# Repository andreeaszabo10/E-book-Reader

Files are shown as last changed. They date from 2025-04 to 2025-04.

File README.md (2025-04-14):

Szabo Cristina-Andreea
# E-book Reader
The project (Openbook) is an E-book reader built around the ESP32-C6-WROOM-1-N8 microcontroller, which integrates Wi-Fi and Bluetooth Low Energy functionality. It is responsible for managing communication between the connected components, sensor data acquisition, and display handling. The E-book reader has a 7.5-inch e-paper display, USB-C charging, a Li-Po battery, and 3 buttons.

## Block diagram:
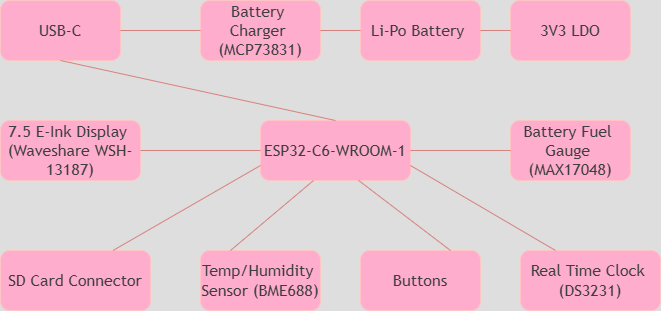
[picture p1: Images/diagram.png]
Block Diagram:

## BOM - Bill of materials
| Component | Device | Link | Datasheet |
|---|---|---|---|
| BOOT_BUTTON | BUTTON_CUSYOMV1 | [Link](https://ro.mouser.com/ProductDetail/Panasonic/EVQ-P7L01P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) | [Datasheet](https://componentsearchengine.com/Datasheets/2/EVQP7L01P.pdf) |
| C1 | ESP32_WROVER_EAGLE-LTSPICE_CC0402 | [Link](https://ro.mouser.com/ProductDetail/YAGEO/CC0402MRX5R5BB106?qs=zEY9bCHj09eCmUJdZuS5Lg%3D%3D)  | [Datasheet](https://componentsearchengine.com/Datasheets/2/CC0402MRX5R5BB106.pdf) |
| C1_BAT | ESP32_WROVER_EAGLE-LTSPICE_CC0402 | [Link](https://ro.mouser.com/ProductDetail/YAGEO/CC0402MRX5R5BB106?qs=zEY9bCHj09eCmUJdZuS5Lg%3D%3D)  | [Datasheet](https://componentsearchengine.com/Datasheets/2/CC0402MRX5R5BB106.pdf) |
| C1_BAT1 | EAGLE-LTSPICE_CC0402 | [Link](https://ro.mouser.com/ProductDetail/YAGEO/CC0402MRX5R5BB106?qs=zEY9bCHj09eCmUJdZuS5Lg%3D%3D)  | [Datasheet](https://componentsearchengine.com/Datasheets/2/CC0402MRX5R5BB106.pdf) |
| C1_BAT2 | EAGLE-LTSPICE_CC0402 | [Link](https://ro.mouser.com/ProductDetail/YAGEO/CC0402MRX5R5BB106?qs=zEY9bCHj09eCmUJdZuS5Lg%3D%3D)  | [Datasheet](https://componentsearchengine.com/Datasheets/2/CC0402MRX5R5BB106.pdf) |
| C2 | ESP32_WROVER_EAGLE-LTSPICE_CC0402 | [Link](https://ro.mouser.com/ProductDetail/YAGEO/CC0402MRX5R5BB106?qs=zEY9bCHj09eCmUJdZuS5Lg%3D%3D)  | [Datasheet](https://componentsearchengine.com/Datasheets/2/CC0402MRX5R5BB106.pdf) |
| C2_BAT | ESP32_WROVER_EAGLE-LTSPICE_CC0402 | [Link](https://ro.mouser.com/ProductDetail/YAGEO/CC0402MRX5R5BB106?qs=zEY9bCHj09eCmUJdZuS5Lg%3D%3D)  | [Datasheet](https://componentsearchengine.com/Datasheets/2/CC0402MRX5R5BB106.pdf) |
| C3 | RCL_CPOL-EUCT3528 | [Link](https://ro.mouser.com/ProductDetail/YAGEO/CC0402MRX5R5BB106?qs=zEY9bCHj09eCmUJdZuS5Lg%3D%3D)  | [Datasheet](https://componentsearchengine.com/Datasheets/2/CC0402MRX5R5BB106.pdf) |
| C4 | ESP32_WROVER_EAGLE-LTSPICE_CC0402 | [Link](https://ro.mouser.com/ProductDetail/YAGEO/CC0402MRX5R5BB106?qs=zEY9bCHj09eCmUJdZuS5Lg%3D%3D)  | [Datasheet](https://componentsearchengine.com/Datasheets/2/CC0402MRX5R5BB106.pdf) |
| C4_USB | ESP32_WROVER_EAGLE-LTSPICE_CC0402 | [Link](https://ro.mouser.com/ProductDetail/YAGEO/CC0402MRX5R5BB106?qs=zEY9bCHj09eCmUJdZuS5Lg%3D%3D)  | [Datasheet](https://componentsearchengine.com/Datasheets/2/CC0402MRX5R5BB106.pdf) |
| C5 | ESP32_WROVER_EAGLE-LTSPICE_CC0402 | [Link](https://ro.mouser.com/ProductDetail/YAGEO/CC0402MRX5R5BB106?qs=zEY9bCHj09eCmUJdZuS5Lg%3D%3D)  | [Datasheet](https://componentsearchengine.com/Datasheets/2/CC0402MRX5R5BB106.pdf) |
| C5_USB | ESP32_WROVER_EAGLE-LTSPICE_CC0402 | [Link](https://ro.mouser.com/ProductDetail/YAGEO/CC0402MRX5R5BB106?qs=zEY9bCHj09eCmUJdZuS5Lg%3D%3D)  | [Datasheet](https://componentsearchengine.com/Datasheets/2/CC0402MRX5R5BB106.pdf) |
| C6 | ESP32_WROVER_EAGLE-LTSPICE_CC0402 | [Link](https://ro.mouser.com/ProductDetail/YAGEO/CC0402MRX5R5BB106?qs=zEY9bCHj09eCmUJdZuS5Lg%3D%3D)  | [Datasheet](https://componentsearchengine.com/Datasheets/2/CC0402MRX5R5BB106.pdf) |
| C7 | ESP32_WROVER_EAGLE-LTSPICE_CC0402 | [Link](https://ro.mouser.com/ProductDetail/YAGEO/CC0402MRX5R5BB106?qs=zEY9bCHj09eCmUJdZuS5Lg%3D%3D)  | [Datasheet](https://componentsearchengine.com/Datasheets/2/CC0402MRX5R5BB106.pdf) |
| C8 | ESP32_WROVER_EAGLE-LTSPICE_CC0402 | [Link](https://ro.mouser.com/ProductDetail/YAGEO/CC0402MRX5R5BB106?qs=zEY9bCHj09eCmUJdZuS5Lg%3D%3D)  | [Datasheet](https://componentsearchengine.com/Datasheets/2/CC0402MRX5R5BB106.pdf) |
| C9 | EAGLE-LTSPICE_CC0402 | [Link](https://ro.mouser.com/ProductDetail/YAGEO/CC0402MRX5R5BB106?qs=zEY9bCHj09eCmUJdZuS5Lg%3D%3D)  | [Datasheet](https://componentsearchengine.com/Datasheets/2/CC0402MRX5R5BB106.pdf) |
| C10 | ESP32_WROVER_EAGLE-LTSPICE_CC0402 | [Link](https://ro.mouser.com/ProductDetail/YAGEO/CC0402MRX5R5BB106?qs=zEY9bCHj09eCmUJdZuS5Lg%3D%3D)  | [Datasheet](https://componentsearchengine.com/Datasheets/2/CC0402MRX5R5BB106.pdf) |
| C10_SUPERCAP | CPH3225A | [Link](https://ro.mouser.com/ProductDetail/Seiko-Semiconductors/CPH3225A?qs=3etwrb1wR%252BhUOph6lAO7eg%3D%3D) | [Datasheet](https://ro.mouser.com/datasheet/2/360/Seiko_Instruments_MicroBattery_E_20230330_2024Jan_-3561061.pdf) |
| CHANGE_BUTTON | BUTTON_CUSYOMV1 | [Link](https://ro.mouser.com/ProductDetail/Panasonic/EVQ-P7L01P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) | [Datasheet](https://componentsearchengine.com/Datasheets/2/EVQP7L01P.pdf) |
| C_DELAY | ESP32_WROVER_EAGLE-LTSPICE_CC0402 | [Link](https://ro.mouser.com/ProductDetail/YAGEO/CC0402MRX5R5BB106?qs=zEY9bCHj09eCmUJdZuS5Lg%3D%3D)  | [Datasheet](https://componentsearchengine.com/Datasheets/2/CC0402MRX5R5BB106.pdf) |
| D1 | USBLC6-2SC6Y | [Link](https://ro.mouser.com/ProductDetail/STMicroelectronics/USBLC6-2SC6Y?qs=gNDSiZmRJS%2FOgDexvXkdow%3D%3D) | [Datasheet](https://ro.mouser.com/datasheet/2/389/usblc6_2sc6y-1852505.pdf) |
| D2 | ESP32_WROVER_AVX...SD0805S020S1R0_AVX_... | [Link](https://eu.mouser.com/ProductDetail/KYOCERA-AVX/SD0805S020S1R0?qs=jCA%252BPfw4LHbpkAoSnwrdjw%3D%3D) | [Datasheet](http://datasheets.avx.com/schottky.pdf) |
| D3 | MBR0530 | [Link](https://www.snapeda.com/parts/MBR0530/Onsemi/view-part/?ref=eda) | [Datasheet](https://www.snapeda.com/parts/MBR0530/Onsemi/view-part/?ref=eda) |
| D4 | MBR0530 | [Link](https://www.snapeda.com/parts/MBR0530/Onsemi/view-part/?ref=eda) | [Datasheet](https://www.snapeda.com/parts/MBR0530/Onsemi/view-part/?ref=eda) |
| D5 | MBR0530 | [Link](https://www.snapeda.com/parts/MBR0530/Onsemi/view-part/?ref=eda) | [Datasheet](https://www.snapeda.com/parts/MBR0530/Onsemi/view-part/?ref=eda) |
| D6 | PGB1010603MR | [Link](https://www.snapeda.com/parts/PGB1010603MR/Littelfuse/view-part/?ref=eda) | [Datasheet](https://www.snapeda.com/parts/PGB1010603MR/Littelfuse/view-part/?ref=eda) |
| D7 | ESP32_WROVER_AVX---SD0805S020S1R0_AVX_... | [Link](https://eu.mouser.com/ProductDetail/KYOCERA-AVX/SD0805S020S1R0?qs=jCA%252BPfw4LHbpkAoSnwrdjw%3D%3D) | [Datasheet](http://datasheets.avx.com/schottky.pdf) |
| D8 | PGB1010603MR | [Link](https://www.snapeda.com/parts/PGB1010603MR/Littelfuse/view-part/?ref=eda) | [Datasheet](https://www.snapeda.com/parts/PGB1010603MR/Littelfuse/view-part/?ref=eda) |
| D9 | PGB1010603MR | [Link](https://www.snapeda.com/parts/PGB1010603MR/Littelfuse/view-part/?ref=eda) | [Datasheet](https://www.snapeda.com/parts/PGB1010603MR/Littelfuse/view-part/?ref=eda) |
| D10 | PGB1010603MR | [Link](https://www.snapeda.com/parts/PGB1010603MR/Littelfuse/view-part/?ref=eda) | [Datasheet](https://www.snapeda.com/parts/PGB1010603MR/Littelfuse/view-part/?ref=eda) |
| D11 | PGB1010603MR | [Link](https://www.snapeda.com/parts/PGB1010603MR/Littelfuse/view-part/?ref=eda) | [Datasheet](https://www.snapeda.com/parts/PGB1010603MR/Littelfuse/view-part/?ref=eda) |
| D12 | PGB1010603MR | [Link](https://www.snapeda.com/parts/PGB1010603MR/Littelfuse/view-part/?ref=eda) | [Datasheet](https://www.snapeda.com/parts/PGB1010603MR/Littelfuse/view-part/?ref=eda) |
| EPD_C1 | ESP32_WROVER_EAGLE-LTSPICE_CC0402 | [Link](https://ro.mouser.com/ProductDetail/YAGEO/CC0402MRX5R5BB106?qs=zEY9bCHj09eCmUJdZuS5Lg%3D%3D)  | [Datasheet](https://componentsearchengine.com/Datasheets/2/CC0402MRX5R5BB106.pdf) |
| EPD_C2 | ESP32_WROVER_EAGLE-LTSPICE_CC0402 | [Link](https://ro.mouser.com/ProductDetail/YAGEO/CC0402MRX5R5BB106?qs=zEY9bCHj09eCmUJdZuS5Lg%3D%3D)  | [Datasheet](https://componentsearchengine.com/Datasheets/2/CC0402MRX5R5BB106.pdf) |
| EPD_C5 | ESP32_WROVER_EAGLE-LTSPICE_CC0402 | [Link](https://ro.mouser.com/ProductDetail/YAGEO/CC0402MRX5R5BB106?qs=zEY9bCHj09eCmUJdZuS5Lg%3D%3D)  | [Datasheet](https://componentsearchengine.com/Datasheets/2/CC0402MRX5R5BB106.pdf) |
| EPD_C6 | ESP32_WROVER_EAGLE-LTSPICE_CC0402 | [Link](https://ro.mouser.com/ProductDetail/YAGEO/CC0402MRX5R5BB106?qs=zEY9bCHj09eCmUJdZuS5Lg%3D%3D)  | [Datasheet](https://componentsearchengine.com/Datasheets/2/CC0402MRX5R5BB106.pdf) |
| EPD_C7 | ESP32_WROVER_EAGLE-LTSPICE_CC0402 | [Link](https://ro.mouser.com/ProductDetail/YAGEO/CC0402MRX5R5BB106?qs=zEY9bCHj09eCmUJdZuS5Lg%3D%3D)  | [Datasheet](https://componentsearchengine.com/Datasheets/2/CC0402MRX5R5BB106.pdf) |
| EPD_C8 | ESP32_WROVER_EAGLE-LTSPICE_CC0402 | [Link](https://ro.mouser.com/ProductDetail/YAGEO/CC0402MRX5R5BB106?qs=zEY9bCHj09eCmUJdZuS5Lg%3D%3D)  | [Datasheet](https://componentsearchengine.com/Datasheets/2/CC0402MRX5R5BB106.pdf) |
| EPD_C9 | ESP32_WROVER_EAGLE-LTSPICE_CC0402 | [Link](https://ro.mouser.com/ProductDetail/YAGEO/CC0402MRX5R5BB106?qs=zEY9bCHj09eCmUJdZuS5Lg%3D%3D)  | [Datasheet](https://componentsearchengine.com/Datasheets/2/CC0402MRX5R5BB106.pdf) |
| EPD_C10 | ESP32_WROVER_EAGLE-LTSPICE_CC0402 | [Link](https://ro.mouser.com/ProductDetail/YAGEO/CC0402MRX5R5BB106?qs=zEY9bCHj09eCmUJdZuS5Lg%3D%3D)  | [Datasheet](https://componentsearchengine.com/Datasheets/2/CC0402MRX5R5BB106.pdf) |
| EPD_C11 | ESP32_WROVER_EAGLE-LTSPICE_CC0402 | [Link](https://ro.mouser.com/ProductDetail/YAGEO/CC0402MRX5R5BB106?qs=zEY9bCHj09eCmUJdZuS5Lg%3D%3D)  | [Datasheet](https://componentsearchengine.com/Datasheets/2/CC0402MRX5R5BB106.pdf) |
| EPD_C12 | ESP32_WROVER_EAGLE-LTSPICE_CC0402 | [Link](https://ro.mouser.com/ProductDetail/YAGEO/CC0402MRX5R5BB106?qs=zEY9bCHj09eCmUJdZuS5Lg%3D%3D)  | [Datasheet](https://componentsearchengine.com/Datasheets/2/CC0402MRX5R5BB106.pdf) |
| IC1 | BD5229G-TR | [Link](https://ro.mouser.com/ProductDetail/ROHM-Semiconductor/BD5229G-TR?qs=4kLU8WoGk0vvnhrrYwdszw%3D%3D) | [Datasheet](https://fscdn.rohm.com/en/products/databook/datasheet/ic/power/voltage_detector/bd52xxg-e.pdf) |
| IC4 | XC6220A331MR-G | [Link](https://ro.mouser.com/ProductDetail/Torex-Semiconductor/XC6220A331MR-G?qs=AsjdqWjXhJ8ZSWznL1J0gg%3D%3D) | [Datasheet](https://ro.mouser.com/datasheet/2/760/xc6220-3371556.pdf) |
| J1 | FH34SRJ-24S-0.5SH_99_ | [Link](https://ro.mouser.com/ProductDetail/Hirose-Connector/FH34SRJ-24S-0.5SH99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) | [Datasheet](https://ro.mouser.com/datasheet/2/185/FH34SRJ_24S_0_5SH_99__CL0580_1255_6_99_2DDrawing_0-1615044.pdf) |
| J2 | USB4110-GF-A | [Link](https://ro.mouser.com/ProductDetail/GCT/USB4110-GF-A?qs=KUoIvG%2F9IlYiZvIXQjyJeA%3D%3D) | [Datasheet](https://ro.mouser.com/datasheet/2/837/GCT_USB4110_Product_Drawing___20k_cycles-3455479.pdf) |
| J3 | QWIIC_CONNECTORJS-1MM | [Link](https://ro.mouser.com/ProductDetail/SparkFun/PRT-14417?qs=wd5RIQLrsJhgdz%2FpmZ%2F3GQ%3D%3D) | [Datasheet](https://ro.mouser.com/datasheet/2/813/Qwiic_Connector_Datasheet-1223982.pdf) |
| J4 | 112A-TAAR-R03_ATTEND  | [Link](https://store.comet.srl.ro/Catalogue/Product/43497/) | [Datasheet](https://store.comet.srl.ro/Catalogue/Product/43497/) |
| L1 | 744043680IND_4828-WE-TPC_WRE | [Link](https://ro.mouser.com/ProductDetail/Wurth-Elektronik/744043680?qs=PGXP4M47uW6VkZq%252BkzjrHA%3D%3D) | [Datasheet](https://eu.mouser.com/ProductDetail/Wurth-Elektronik/744043680?qs=PGXP4M47uW6VkZq%252BkzjrHA%3D%3D) |
| PFMF.050.1 | ESP32C6_VARISTORCN1812 | [Link](https://ro.mouser.com/ProductDetail/KEMET/VE1812K401R050?qs=OycAS1CGnlizCtaoDVbQTA%3D%3D) | [Datasheet](https://www.mouser.co.uk/ProductDetail/EPCOS-TDK/B72520T0350K062?qs=dEfas%2FXlABIszF52uu7vrg%3D%3D) |
| Q1 | DMG2305UX-7 | [Link](https://ro.mouser.com/ProductDetail/Diodes-Incorporated/DMG2305UX-7?qs=L1DZKBg7t5F%2FNBHrjfxC%252Bg%3D%3D) | [Datasheet](https://www.diodes.com/assets/Datasheets/DMG2305UX.pdf) |
| Q2 | ESP32_WROVER_SPARKFUN-DISCRETESEMI_MOSFET_... | [Link](https://ro.mouser.com/ProductDetail/Diodes-Incorporated/DMG2305UX-7?qs=L1DZKBg7t5F%2FNBHrjfxC%252Bg%3D%3D) | [Datasheet](https://www.diodes.com/assets/Datasheets/DMG2305UX.pdf) |
| Q3 | D8 | [Link](https://ro.mouser.com/ProductDetail/Vishay-Semiconductors/SI1308EDL-T1-GE3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) | [Datasheet](https://componentsearchengine.com/part-view/SI1308EDL-T1-GE3/Vishay) |
| R1 | ESP32_WROVER_EAGLE-LTSPICE_RR0402 | [Link](https://ro.mouser.com/ProductDetail/YAGEO/RC0402FR-07100KL?qs=mnq%2FyloZIXzTlUn7JAHSWg%3D%3D) | [Datasheet](https://ro.mouser.com/datasheet/2/447/YAGEO_PYu_RC_Group_51_RoHS_L_12-3313492.pdf) |
| R1_PINH | ESP32_WROVER_EAGLE-LTSPICE_RR0402 | [Link](https://ro.mouser.com/ProductDetail/YAGEO/RC0402FR-07100KL?qs=mnq%2FyloZIXzTlUn7JAHSWg%3D%3D) | [Datasheet](https://ro.mouser.com/datasheet/2/447/YAGEO_PYu_RC_Group_51_RoHS_L_12-3313492.pdf) |
| R1_PINH1 | ESP32_WROVER_EAGLE-LTSPICE_RR0402 | [Link](https://ro.mouser.com/ProductDetail/YAGEO/RC0402FR-07100KL?qs=mnq%2FyloZIXzTlUn7JAHSWg%3D%3D) | [Datasheet](https://ro.mouser.com/datasheet/2/447/YAGEO_PYu_RC_Group_51_RoHS_L_12-3313492.pdf) |
| R1_BAT | ESP32_WROVER_EAGLE-LTSPICE_RR0402 | [Link](https://ro.mouser.com/ProductDetail/YAGEO/RC0402FR-07100KL?qs=mnq%2FyloZIXzTlUn7JAHSWg%3D%3D) | [Datasheet](https://ro.mouser.com/datasheet/2/447/YAGEO_PYu_RC_Group_51_RoHS_L_12-3313492.pdf) |
| R1_PWRUSB | ESP32_WROVER_EAGLE-LTSPICE_RR0402 | [Link](https://ro.mouser.com/ProductDetail/YAGEO/RC0402FR-07100KL?qs=mnq%2FyloZIXzTlUn7JAHSWg%3D%3D) | [Datasheet](https://ro.mouser.com/datasheet/2/447/YAGEO_PYu_RC_Group_51_RoHS_L_12-3313492.pdf) |
| R2 | ESP32_WROVER_EAGLE-LTSPICE_RR0402 | [Link](https://ro.mouser.com/ProductDetail/YAGEO/RC0402FR-07100KL?qs=mnq%2FyloZIXzTlUn7JAHSWg%3D%3D) | [Datasheet](https://ro.mouser.com/datasheet/2/447/YAGEO_PYu_RC_Group_51_RoHS_L_12-3313492.pdf) |
| R2_PINH | ESP32_WROVER_EAGLE-LTSPICE_RR0402 | [Link](https://ro.mouser.com/ProductDetail/YAGEO/RC0402FR-07100KL?qs=mnq%2FyloZIXzTlUn7JAHSWg%3D%3D) | [Datasheet](https://ro.mouser.com/datasheet/2/447/YAGEO_PYu_RC_Group_51_RoHS_L_12-3313492.pdf) |
| R2_PINH1 | ESP32_WROVER_EAGLE-LTSPICE_RR0402 | [Link](https://ro.mouser.com/ProductDetail/YAGEO/RC0402FR-07100KL?qs=mnq%2FyloZIXzTlUn7JAHSWg%3D%3D) | [Datasheet](https://ro.mouser.com/datasheet/2/447/YAGEO_PYu_RC_Group_51_RoHS_L_12-3313492.pdf) |
| R2_USB | ESP32_WROVER_EAGLE-LTSPICE_RR0402 | [Link](https://ro.mouser.com/ProductDetail/YAGEO/RC0402FR-07100KL?qs=mnq%2FyloZIXzTlUn7JAHSWg%3D%3D) | [Datasheet](https://ro.mouser.com/datasheet/2/447/YAGEO_PYu_RC_Group_51_RoHS_L_12-3313492.pdf) |
| R2_USB1 | ESP32_WROVER_EAGLE-LTSPICE_RR0402 | [Link](https://ro.mouser.com/ProductDetail/YAGEO/RC0402FR-07100KL?qs=mnq%2FyloZIXzTlUn7JAHSWg%3D%3D) | [Datasheet](https://ro.mouser.com/datasheet/2/447/YAGEO_PYu_RC_Group_51_RoHS_L_12-3313492.pdf) |
| R2_BAT | ESP32_WROVER_EAGLE-LTSPICE_RR0402 | [Link](https://ro.mouser.com/ProductDetail/YAGEO/RC0402FR-07100KL?qs=mnq%2FyloZIXzTlUn7JAHSWg%3D%3D) | [Datasheet](https://ro.mouser.com/datasheet/2/447/YAGEO_PYu_RC_Group_51_RoHS_L_12-3313492.pdf) |
| R3 | ESP32_WROVER_EAGLE-LTSPICE_RR0402 | [Link](https://ro.mouser.com/ProductDetail/YAGEO/RC0402FR-07100KL?qs=mnq%2FyloZIXzTlUn7JAHSWg%3D%3D) | [Datasheet](https://ro.mouser.com/datasheet/2/447/YAGEO_PYu_RC_Group_51_RoHS_L_12-3313492.pdf) |
| R4 | ESP32_WROVER_EAGLE-LTSPICE_RR0402 | [Link](https://ro.mouser.com/ProductDetail/YAGEO/RC0402FR-07100KL?qs=mnq%2FyloZIXzTlUn7JAHSWg%3D%3D) | [Datasheet](https://ro.mouser.com/datasheet/2/447/YAGEO_PYu_RC_Group_51_RoHS_L_12-3313492.pdf) |
| R5 | ESP32_WROVER_EAGLE-LTSPICE_RR0402 | [Link](https://ro.mouser.com/ProductDetail/YAGEO/RC0402FR-07100KL?qs=mnq%2FyloZIXzTlUn7JAHSWg%3D%3D) | [Datasheet](https://ro.mouser.com/datasheet/2/447/YAGEO_PYu_RC_Group_51_RoHS_L_12-3313492.pdf) |
| R6 | ESP32_WROVER_EAGLE-LTSPICE_RR0402 | [Link](https://ro.mouser.com/ProductDetail/YAGEO/RC0402FR-07100KL?qs=mnq%2FyloZIXzTlUn7JAHSWg%3D%3D) | [Datasheet](https://ro.mouser.com/datasheet/2/447/YAGEO_PYu_RC_Group_51_RoHS_L_12-3313492.pdf) |
| R7 | ESP32_WROVER_EAGLE-LTSPICE_RR0402 | [Link](https://ro.mouser.com/ProductDetail/YAGEO/RC0402FR-07100KL?qs=mnq%2FyloZIXzTlUn7JAHSWg%3D%3D) | [Datasheet](https://ro.mouser.com/datasheet/2/447/YAGEO_PYu_RC_Group_51_RoHS_L_12-3313492.pdf) |
| R8 | ESP32_WROVER_EAGLE-LTSPICE_RR0402 | [Link](https://ro.mouser.com/ProductDetail/YAGEO/RC0402FR-07100KL?qs=mnq%2FyloZIXzTlUn7JAHSWg%3D%3D) | [Datasheet](https://ro.mouser.com/datasheet/2/447/YAGEO_PYu_RC_Group_51_RoHS_L_12-3313492.pdf) |
| R9 | ESP32_WROVER_EAGLE-LTSPICE_RR0402 | [Link](https://ro.mouser.com/ProductDetail/YAGEO/RC0402FR-07100KL?qs=mnq%2FyloZIXzTlUn7JAHSWg%3D%3D) | [Datasheet](https://ro.mouser.com/datasheet/2/447/YAGEO_PYu_RC_Group_51_RoHS_L_12-3313492.pdf) |
| R10 | ESP32_WROVER_EAGLE-LTSPICE_RR0402 | [Link](https://ro.mouser.com/ProductDetail/YAGEO/RC0402FR-07100KL?qs=mnq%2FyloZIXzTlUn7JAHSWg%3D%3D) | [Datasheet](https://ro.mouser.com/datasheet/2/447/YAGEO_PYu_RC_Group_51_RoHS_L_12-3313492.pdf) |
| RESET_BUTTON | BUTTON_CUSYOMV1 | [Link](https://ro.mouser.com/ProductDetail/Panasonic/EVQ-P7L01P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) | [Datasheet](https://componentsearchengine.com/Datasheets/2/EVQP7L01P.pdf) |
| R_BOOT | ESP32_WROVER_EAGLE-LTSPICE_RR0402 | [Link](https://ro.mouser.com/ProductDetail/YAGEO/RC0402FR-07100KL?qs=mnq%2FyloZIXzTlUn7JAHSWg%3D%3D) | [Datasheet](https://ro.mouser.com/datasheet/2/447/YAGEO_PYu_RC_Group_51_RoHS_L_12-3313492.pdf) |
| R_CAPACITOR | ESP32_WROVER_EAGLE-LTSPICE_RR0402 | [Link](https://ro.mouser.com/ProductDetail/YAGEO/RC0402FR-07100KL?qs=mnq%2FyloZIXzTlUn7JAHSWg%3D%3D) | [Datasheet](https://ro.mouser.com/datasheet/2/447/YAGEO_PYu_RC_Group_51_RoHS_L_12-3313492.pdf) |
| R_CHANGE | ESP32_WROVER_EAGLE-LTSPICE_RR0402 | [Link](https://ro.mouser.com/ProductDetail/YAGEO/RC0402FR-07100KL?qs=mnq%2FyloZIXzTlUn7JAHSWg%3D%3D) | [Datasheet](https://ro.mouser.com/datasheet/2/447/YAGEO_PYu_RC_Group_51_RoHS_L_12-3313492.pdf) |
| R_CL1 | ESP32_WROVER_EAGLE-LTSPICE_RR0402 | [Link](https://ro.mouser.com/ProductDetail/YAGEO/RC0402FR-07100KL?qs=mnq%2FyloZIXzTlUn7JAHSWg%3D%3D) | [Datasheet](https://ro.mouser.com/datasheet/2/447/YAGEO_PYu_RC_Group_51_RoHS_L_12-3313492.pdf) |
| R_RESET | ESP32_WROVER_EAGLE-LTSPICE_RR0402 | [Link](https://ro.mouser.com/ProductDetail/YAGEO/RC0402FR-07100KL?qs=mnq%2FyloZIXzTlUn7JAHSWg%3D%3D) | [Datasheet](https://ro.mouser.com/datasheet/2/447/YAGEO_PYu_RC_Group_51_RoHS_L_12-3313492.pdf) |
| SENSOR2 | ESP32_WROVER_BME680_BME680 | [Link](https://ro.mouser.com/ProductDetail/Bosch-Sensortec/BME680?qs=v271MhAjFHjo0yA%2FC4OnDQ%3D%3D) | [Datasheet](https://ro.mouser.com/datasheet/2/783/BST_BME680_DS001-1509608.pdf) |
| SJ1 | SJ | [Link](https://grabcad.com/library/solder-jumpers-1) | [Datasheet](https://grabcad.com/library/solder-jumpers-1) |
| TP1 - TP17 | TPTP20R | - | - |
| U1 | W25Q512JVEIQ | [Link](https://ro.mouser.com/ProductDetail/Winbond/W25Q512JVEIQ?qs=l7cgNqFNU1jw6svr3at6tA%3D%3D) | [Datasheet](https://ro.mouser.com/datasheet/2/949/Winbond_W25Q512JV_Datasheet-3240039.pdf) |
| U2 | ESP32-C6-WROOM-1-N8 | [Link](https://ro.mouser.com/ProductDetail/Espressif-Systems/ESP32-C6-WROOM-1-N8?qs=8Wlm6%252BaMh8ST02Gmwp74cw%3D%3D) | [Datasheet](https://ro.mouser.com/datasheet/2/891/Espressif_ESP32_C6_WROOM_1__Datasheet_V0_1_PRELIMI-3239987.pdf) |
| U3 | DS3231SN# | [Link](https://ro.mouser.com/ProductDetail/Analog-Devices-Maxim-Integrated/DS3231SN?qs=1eQvB6Dk1vhUlr8%2FOrV0Fw%3D%3D) | [Datasheet](https://ro.mouser.com/datasheet/2/609/DS3231-3421123.pdf) |
| U4 | MAX17048G+T10 | [Link](https://ro.mouser.com/ProductDetail/Analog-Devices-Maxim-Integrated/MAX17048G%2bT10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) | [Datasheet](https://ro.mouser.com/datasheet/2/609/MAX17048_MAX17049-3469099.pdf) |
| U5 | ESP32_WROVER_SPARKFUN-IC-POWER_MCP73831 | [Link](https://ro.mouser.com/ProductDetail/Microchip-Technology/MCP73831T-2ACI-OT?qs=yUQqVecv4qvbBQBGbHx0Mw%3D%3D) | [Datasheet](https://ro.mouser.com/datasheet/2/268/MCP73831_Family_Data_Sheet_DS20001984H-3441711.pdf) |

## Hardware description:
- ESP32-C6-WROOM-1-N8: The most important part of the system, providing Wi-Fi and BLE capabilities for wireless communication.
- BME688: An environmental and air quality sensor that measures temperature, humidity, pressure, and gas. It communicates with the ESP32 via the I2C protocol.
- DS3231SN: A high-precision Real-Time Clock (RTC) module, connected via I2C.
- MAX17048: A battery level monitor with I2C interface, used to provide the State of Charge (SOC) estimation for the battery.
- SD Card Module: Provides local data storage, communicating with the ESP32 using the SPI protocol for faster read/write operations.
- E-Ink Display: A low-power e-paper display with an SPI interface for minimal energy consumption. It includes the following control signals: EPD_CS, EPD_DC, EPD_RST, and EPD_BUSY.
- W25Q512JVEIQ (64MB NOR Flash): External flash memory connected via SPI, used for storing firmware or large datasets.
- BOOT and RESET Buttons: Connected to GPIO pins to manage the bootloader activation and system reset.
- MCP73831: A Li-Po battery charging controller, responsible for managing the charging process of the battery.
- XC6220A331MR-G (LDO Regulator): A 3.3V voltage regulator that powers the logic circuits of the system from the battery or USB input.
- USB-C Port (USB4110-GF-A): Provides power input and serves as the serial interface for code uploading and debugging.

## Pins description:
- IO0 - INT_RTC: Interrupt signal from the RTC that can wake up the ESP32 from deep sleep. This pin is used by the RTC.
- IO1 – 32KHZ: The 32.768 kHz clock output from the DS3231 RTC, routed to the ESP32 for accurate timekeeping.
- IO2 – MISO: This is the Master In Slave Out pin for SPI communication, used for NOR Flash, E-Paper, and microSD data transfer.
- IO3 - EPD_BUSY: E-Ink Display status signal that indicates whether the screen is busy. The ESP32 reads this to determine when it can send the next display update.
- IO4 – SS_SD: SPI Select pin for the microSD card, ensuring it does not conflict with other SPI devices using Chip Select (CS) lines.
- IO5 – EPD_DC: E-Ink Display Data/Command line used to differentiate between command and data states.
- IO6 – SCK: The SPI Clock pin, used to synchronize data transmission for peripherals like NOR Flash, E-Paper, and microSD.
- IO7 – MOSI: Master Out Slave In pin for SPI communication, used to send data to NOR Flash, E-Paper, and microSD.
- IO9 – IO/BOOT: This is a GPIO pin used for entering programming mode and activating the bootloader when the system is powered on.
- IO10 - EPD_CS: E-Ink Display Chip Select pin, allowing the display to be selected during SPI communication without interfering with other devices.
- IO11 – FLASH_CS: Chip Select pin for the NOR Flash memory, used to activate the flash memory module during SPI communication.
- IO12 – USB_D-: USB Data- line, directly connected to the USB-C connector, enabling power input and data transfer for code uploading and debugging.
- IO13 – USB_D+: USB Data+ line, also routed to the USB-C connector, enabling data transfer for serial communication and debugging.
- IO15 – IO/CHANGE: A GPIO pin used for user-defined actions, such as navigating between pages or changing modes.
- IO16 – TX: Serial Transmit pin used for flashing the older ESP chips and for serial debug logs.
- IO17 – RX: Serial Receive pin used for receiving data during flashing and for serial communication in debug mode.
- IO18 – RTC_RST: Manual Reset pin for the RTC module. It can be used to reset the RTC for synchronization or during a watchdog reset.
- IO19 – I2C_PW: Provides 3.3V to power I2C peripherals, including the RTC, BME688, and battery gauge modules.
- IO20 – EPD_3V3_C: A 3.3V supply line dedicated to powering the E-Ink Display.
- IO21 – SDA: I2C Data line used for communication with the RTC, BME688, and other I2C devices.
- IO22 – SCL: I2C Clock line used for synchronization of data transfer between the ESP32 and I2C devices.
- IO23 – EPD_RST: E-Ink Display Reset pin used to initialize the display before any updates or during power-up.

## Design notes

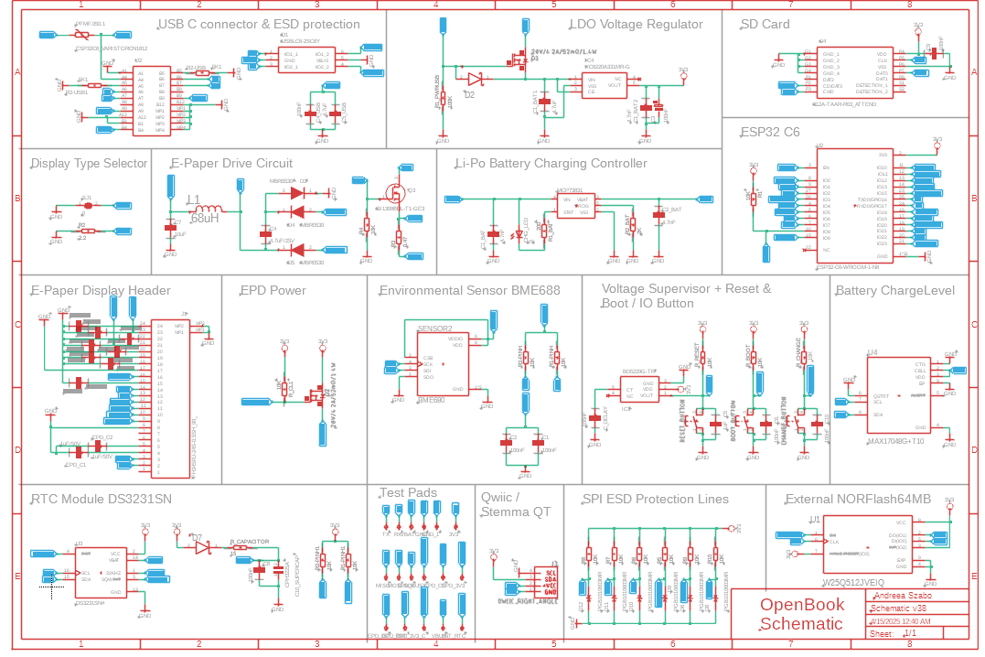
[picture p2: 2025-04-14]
Images/schematic.png

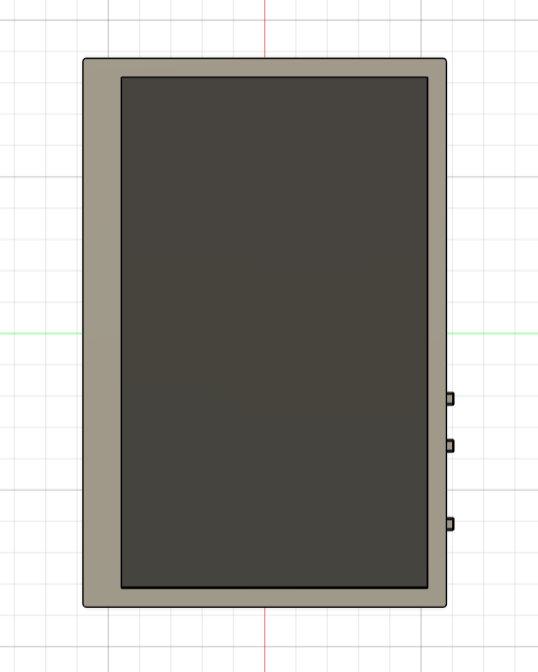
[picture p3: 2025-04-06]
Images/case_front.png

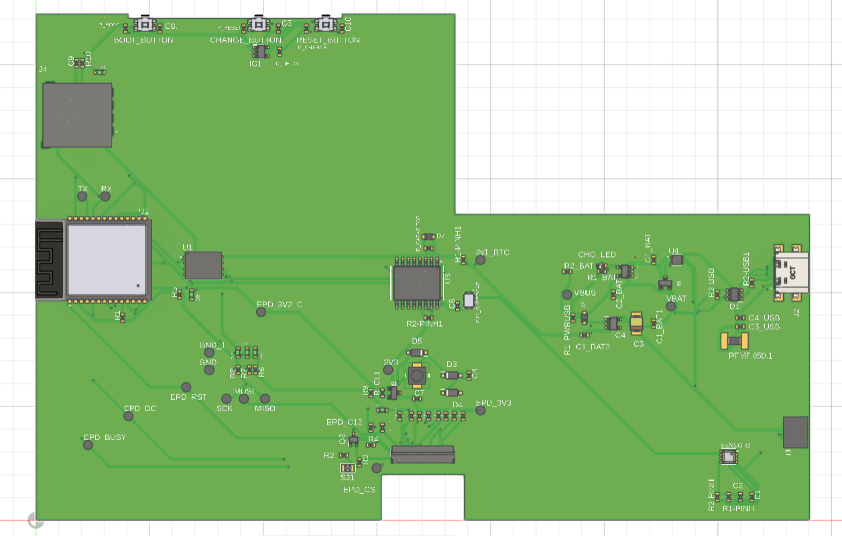
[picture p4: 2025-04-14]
Images/3d_pcb.png

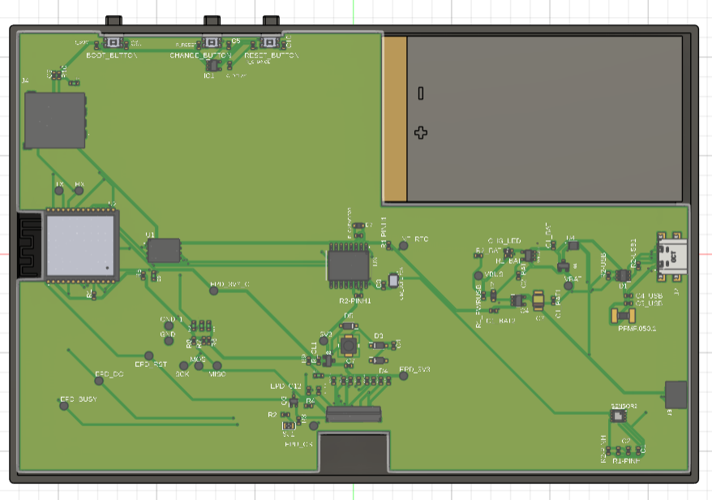
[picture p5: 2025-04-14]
Images/3d_in_case.png

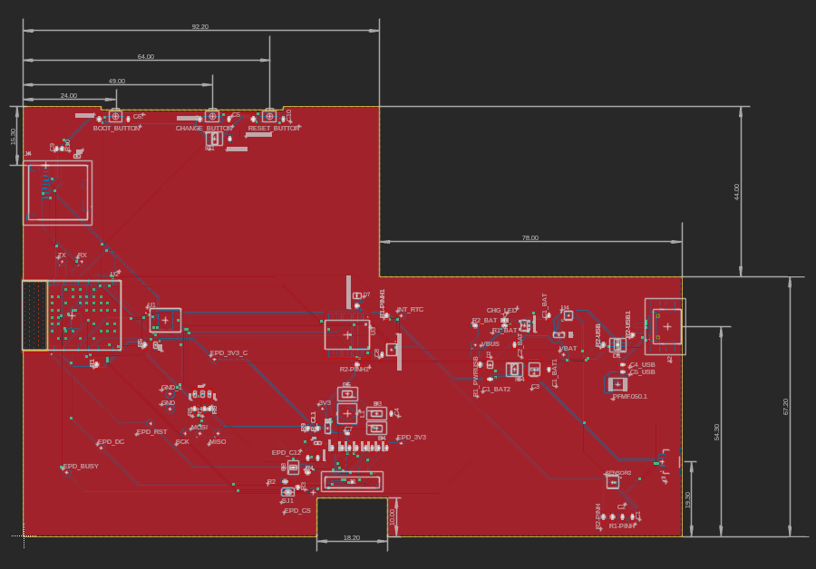
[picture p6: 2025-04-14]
Images/top.png

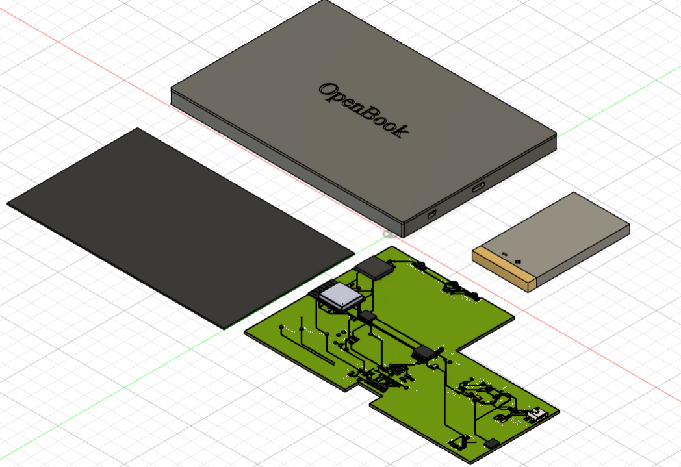
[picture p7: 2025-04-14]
Images/exploded_view.png

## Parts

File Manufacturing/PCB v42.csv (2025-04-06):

Qty | Value | Device | Package | Parts | Description | ARROW_PART_NUMBER | ARROW_PRICE-STOCK | AVAILABILITY | CENTROID_NOT_SPECIFIED | CHECK_PRICES | COPYRIGHT | DATASHEET | DESCRIPTION | DIGIKEY_DESCRIPTION | DIGIKEY_PART_NUMBER | HEIGHT | LEAD_FREE | MANUFACTURER_NAME | MANUFACTURER_PART_NUMBER | MF | MFR_NAME | MOUSER_PART_NUMBER | MOUSER_PRICE-STOCK | MOUSER_TESTING_PART_NUMBER | MOUSER_TESTING_PRICE-STOCK | MP | MPN | PACKAGE | POPULARITY | PREFIX | PRICE | PROD_ID | PURCHASE-URL | ROHS | SNAPEDA_LINK | SPICEMODEL | SPICEPREFIX | TEMPERATURE_RANGE_HIGH | TEMPERATURE_RANGE_LOW | TP_SIGNAL_NAME | VALUE
1 |  | ADAFRUIT_LEDCHIP-LED0603 | ADAFRUIT_CHIP-LED0603 | CHG_LED | LED
1 |  | EAGLE-LTSPICE_CC0402 | ESP32_WROVER_EAGLE-LTSPICE_C0402 | EPD_C9 | CAPACITOR, European symbol |  |  |  |  |  |  |  |  |  |  |  |  |  |  |  |  |  |  |  |  |  |  |  |  |  |  |  |  |  |  | NONE | C
1 |  | SJ | SJ | SJ1 | SMD solder JUMPER |  |  |  |  |  |  |  |  |  |  |  |  |  |  |  |  |  |  |  |  |  |  |  | 3
1 | 0.1uF/50V | EAGLE-LTSPICE_CC0402 | ESP32_WROVER_EAGLE-LTSPICE_C0402 | EPD_C5 | CAPACITOR, European symbol |  |  |  |  |  |  |  |  |  |  |  |  |  |  |  |  |  |  |  |  |  |  |  |  |  |  |  |  |  |  | NONE | C
1 | 0.47 | ESP32_WROVER_EAGLE-LTSPICE_RR0402 | ESP32_WROVER_EAGLE-LTSPICE_R0402 | R3 | RESISTOR, European symbol |  |  |  |  |  |  |  |  |  |  |  |  |  |  |  |  |  |  |  |  |  |  |  |  |  |  |  |  |  |  | NONE | R
1 | 100K | ESP32_WROVER_EAGLE-LTSPICE_RR0402 | ESP32_WROVER_EAGLE-LTSPICE_R0402 | R1_PWRUSB | RESISTOR, European symbol |  |  |  |  |  |  |  |  |  |  |  |  |  |  |  |  |  |  |  |  |  |  |  |  |  |  |  |  |  |  | NONE | R
8 | 100nF | EAGLE-LTSPICE_CC0402 | ESP32_WROVER_EAGLE-LTSPICE_C0402 | C1, C2, C4_USB, C6., C8, C9, C10, C_DELAY | CAPACITOR, European symbol |  |  |  |  |  |  |  |  |  |  |  |  |  |  |  |  |  |  |  |  |  |  |  |  |  |  |  |  |  |  | NONE | C
1 | 100nF | RCL_CPOL-EUCT3528 | RCL_CT3528 | C3 | POLARIZED CAPACITOR, European symbol |  |  |  |  |  |  |  |  |  |  |  |  |  |  |  |  |  |  |  |  |  |  |  | 0 |  |  |  |  |  |  |  | C
16 | 10K | ESP32_WROVER_EAGLE-LTSPICE_RR0402 | ESP32_WROVER_EAGLE-LTSPICE_R0402 | R1, R1-PINH, R1-PINH1, R2-PINH, R2-PINH1, R4, R5, R6, R7, R8, R9, R10, R_BOOT, R_CHANGE, R_CL1, R_RESET | RESISTOR, European symbol |  |  |  |  |  |  |  |  |  |  |  |  |  |  |  |  |  |  |  |  |  |  |  |  |  |  |  |  |  |  | NONE | R
1 | 10uF | EAGLE-LTSPICE_CC0402 | ESP32_WROVER_EAGLE-LTSPICE_C0402 | C7 | CAPACITOR, European symbol |  |  |  |  |  |  |  |  |  |  |  |  |  |  |  |  |  |  |  |  |  |  |  |  |  |  |  |  |  |  | NONE | C
1 | 112A-TAAR-R03_ATTEND | 112A-TAAR-R03_ATTEND | 112ATAARR03ATTEND | J4 | Micro SD Card Socket, Push-Push Type, Top Mount, SMT, H=1.83mm, 10u |  |  |  |  |  |  |  | Micro SD Card Socket | Push-Push Type | Top Mount | SMT | H=1.83mm | 10u |  |  | 1.9mm |  | ATTEND | 112A-TAAR-R03 ATTEND
1 | 15 | ESP32_WROVER_EAGLE-LTSPICE_RR0402 | ESP32_WROVER_EAGLE-LTSPICE_R0402 | R_CAPACITOR | RESISTOR, European symbol |  |  |  |  |  |  |  |  |  |  |  |  |  |  |  |  |  |  |  |  |  |  |  |  |  |  |  |  |  |  | NONE | R
1 | 1uF | EAGLE-LTSPICE_CC0402 | ESP32_WROVER_EAGLE-LTSPICE_C0402 | C5 | CAPACITOR, European symbol |  |  |  |  |  |  |  |  |  |  |  |  |  |  |  |  |  |  |  |  |  |  |  |  |  |  |  |  |  |  | NONE | C
8 | 1uF/50V | EAGLE-LTSPICE_CC0402 | ESP32_WROVER_EAGLE-LTSPICE_C0402 | EPD_C1, EPD_C2, EPD_C6, EPD_C7, EPD_C8, EPD_C10, EPD_C11, EPD_C12 | CAPACITOR, European symbol |  |  |  |  |  |  |  |  |  |  |  |  |  |  |  |  |  |  |  |  |  |  |  |  |  |  |  |  |  |  | NONE | C
1 | 2.2 | ESP32_WROVER_EAGLE-LTSPICE_RR0402 | ESP32_WROVER_EAGLE-LTSPICE_R0402 | R2 | RESISTOR, European symbol |  |  |  |  |  |  |  |  |  |  |  |  |  |  |  |  |  |  |  |  |  |  |  |  |  |  |  |  |  |  | NONE | R
1 | 200 | ESP32_WROVER_EAGLE-LTSPICE_RR0402 | ESP32_WROVER_EAGLE-LTSPICE_R0402 | R1_BAT | RESISTOR, European symbol |  |  |  |  |  |  |  |  |  |  |  |  |  |  |  |  |  |  |  |  |  |  |  |  |  |  |  |  |  |  | NONE | R
2 | 20V/4.2A/52mO/1.4W | ESP32_WROVER_SPARKFUN-DISCRETESEMI_MOSFET_PCH-DMG2305UX-7 | ESP32_WROVER_SPARKFUN-DISCRETESEMI_SOT23-3 | Q1, Q2 | P-channel MOSFETs |  |  |  |  |  |  |  |  |  |  |  |  |  |  |  |  |  |  |  |  |  |  |  |  |  |  | TRAN-14388 |  |  |  |  |  |  |  |  | 20V/4.2A/52mO/1.4W
1 | 2K | ESP32_WROVER_EAGLE-LTSPICE_RR0402 | ESP32_WROVER_EAGLE-LTSPICE_R0402 | R2_BAT | RESISTOR, European symbol |  |  |  |  |  |  |  |  |  |  |  |  |  |  |  |  |  |  |  |  |  |  |  |  |  |  |  |  |  |  | NONE | R
3 | 4.7nF | EAGLE-LTSPICE_CC0402 | ESP32_WROVER_EAGLE-LTSPICE_C0402 | C1_BAT, C1_BAT2, C2_BAT | CAPACITOR, European symbol |  |  |  |  |  |  |  |  |  |  |  |  |  |  |  |  |  |  |  |  |  |  |  |  |  |  |  |  |  |  | NONE | C
2 | 4.7uF | EAGLE-LTSPICE_CC0402 | ESP32_WROVER_EAGLE-LTSPICE_C0402 | C1_BAT1, C5_USB | CAPACITOR, European symbol |  |  |  |  |  |  |  |  |  |  |  |  |  |  |  |  |  |  |  |  |  |  |  |  |  |  |  |  |  |  | NONE | C
1 | 4.7uF/25V | EAGLE-LTSPICE_CC0402 | ESP32_WROVER_EAGLE-LTSPICE_C0402 | C4 | CAPACITOR, European symbol |  |  |  |  |  |  |  |  |  |  |  |  |  |  |  |  |  |  |  |  |  |  |  |  |  |  |  |  |  |  | NONE | C
2 | 5K1 | ESP32_WROVER_EAGLE-LTSPICE_RR0402 | ESP32_WROVER_EAGLE-LTSPICE_R0402 | R2-USB, R2-USB1 | RESISTOR, European symbol |  |  |  |  |  |  |  |  |  |  |  |  |  |  |  |  |  |  |  |  |  |  |  |  |  |  |  |  |  |  | NONE | R
1 | 68uH | 744043680IND_4828-WE-TPC_WRE | IND_4828-WE-TPC_WRE | L1 |  |  |  |  |  |  | Copyright (C) 2024 Ultra Librarian. All rights reserved. |  |  |  |  |  |  |  | 744043680 |  | Wurth Electronics
1 | BD5229G-TR | BD5229G-TR | SOT95P280X125-5N | IC1 | Voltage Detector with Adjustable Delay Time: CMOS processes are utilized to develop high precision, low current consumption CMOS reset ICs that allow arbitrary setting of the delay time. The extensive lineup includes both Nch Open Drain and CMOS output types in a wide range of detection voltages (from 2.3V to 6.0V, in 0.1V steps), enabling selection of the ideal solution based on customer requirements. In addition, the entire series is of course both lead-free and RoHS-compliant. |  |  |  |  |  |  |  | Voltage Detector with Adjustable Delay Time: CMOS processes are utilized to develop high precision | low current consumption CMOS reset ICs that allow arbitrary setting of the delay time. The extensive lineup includes both Nch Open Drain and CMOS output types in a wide range of detection voltages (from 2.3V to 6.0V | in 0.1V steps) | enabling selection of the ideal solution based on customer requirements. In addition | the entire series is of course both lead-free and RoHS-compliant. |  |  | 1.25mm |  | ROHM Semiconductor | BD5229G-TR |  |  | 755-BD5229G-TR | https://www.mouser.co.uk/ProductDetail/ROHM-Semiconductor/BD5229G-TR?qs=4kLU8WoGk0vvnhrrYwdszw%3D%3D
1 | BME680 | ESP32_WROVER_BME680_BME680 | ESP32_WROVER_BME680_PSON80P300X300X100-8N | SENSOR2 | Integrated Environmental Unit |  |  | Unavailable |  |  |  |  | Integrated Environmental Unit |  |  |  |  |  |  | Bosch Sensortec |  |  |  |  |  | BME680 |  | LGA-8 Bosch Tools |  |  | None
3 | BUTTON_CUSYOMV1 | BUTTON_CUSYOMV1 | MYBUTTON | BOOT_BUTTON, CHANGE_BUTTON, RESET_BUTTON
1 | CPH3225A | CPH3225A | CAPCP3225X100N | C10_SUPERCAP | Cap 0.011F 3.3V 1210 Flat Check availability |  |  | Not in stock |  | https://www.snapeda.com/parts/CPH3225A/Seiko+Instruments/view-part/?ref=eda |  |  | 11 mF (EDLC) Supercapacitor 3.3 V 1210 (3225 Metric) - - |  |  |  |  |  |  | Seiko Instruments |  |  |  |  |  | CPH3225A |  | 1210 Seiko |  |  | None |  | https://www.snapeda.com/api/url_track_click_mouser/?unipart_id=562593&manufacturer=Seiko Instruments&part_name=CPH3225A&search_term=None |  | https://www.snapeda.com/parts/CPH3225A/Seiko+Instruments/view-part/?ref=snap
1 | DS3231SN# | DS3231SN# | SOIC127P1032X265-16N | U3 | Real Time Clock Serial 16-Pin SOIC W T/R Check availability |  |  | In Stock |  | https://www.snapeda.com/parts/DS3231SN%23/Analog+Devices/view-part/?ref=eda |  |  | Extremely Accurate I²C-Integrated RTC/TCXO/Crystal |  |  |  |  |  |  | Analog Devices |  |  |  |  |  | DS3231SN# |  | SOIC-16 Maxim |  |  | None |  | https://www.snapeda.com/api/url_track_click_mouser/?unipart_id=99048&manufacturer=Analog Devices&part_name=DS3231SN#&search_term=None |  | https://www.snapeda.com/parts/DS3231SN%23/Analog+Devices/view-part/?ref=snap
1 | ESP32-C6-WROOM-1-N8 | ESP32-C6-WROOM-1-N8 | XCVR_ESP32-C6-WROOM-1-N8 | U2 | Check availability |  |  | In Stock |  | https://www.snapeda.com/parts/ESP32-C6-WROOM-1-N8/Espressif+Systems/view-part/?ref=eda |  |  | Multiprotocol Modules ESP32-C6 module | Wi-Fi 6 in 2.4 GHz band | Bluetooth 5 | Zigbee 3.0 and Thread. ESP34-WROOM Compatible - ENGINEERING SAMPLE |  |  |  |  |  |  | Espressif Systems |  |  |  |  |  | ESP32-C6-WROOM-1-N8 |  | None |  |  | None |  |  |  | https://www.snapeda.com/parts/ESP32-C6-WROOM-1-N8/Espressif+Systems/view-part/?ref=snap
1 | ESP32C6_VARISTORCN1812 | ESP32C6_VARISTORCN1812 | ESP32C6_VARISTOR_CT/CN1812 | PFMF.050.1 | VARISTOR |  |  |  |  |  |  |  |  |  |  |  |  |  |  |  |  |  |  |  |  |  |  |  | 0
1 | ESP32_WROVER_AVX---SD0805S020S1R0_AVX_SD0805S020S1R0_0_0AVX_SD0805S020S1R0_0_0 | ESP32_WROVER_AVX---SD0805S020S1R0_AVX_SD0805S020S1R0_0_0AVX_SD0805S020S1R0_0_0 | ESP32_WROVER_AVX---SD0805S020S1R0_AVX_SD0805S020S1R0_0 | D2 | Schottky Barrier Rectifier Diode |  |  |  | No |  |  | http://datasheets.avx.com/schottky.pdf |  | DIODE SCHOTTKY 20V 1A 0805 | 478-7800-1-ND |  | yes |  |  | AVX |  | 581-SD0805S020S1R0 |  |  |  |  |  | 0805 (2012 metric) |  | D |  |  |  | yes |  |  |  | +125°C | -55°C
1 | FH34SRJ-24S-0.5SH_99_ | FH34SRJ-24S-0.5SH_99_ | FH34SRJ24S05SH99 | J1 | (0.50mm) Surface Mount, Right Angle |  |  |  |  |  |  |  | 24 Position FFC | FPC Connector Contacts | (0.50mm) Surface Mount | Right Angle |  |  | 1.1mm |  | Hirose | FH34SRJ-24S-0.5SH(99) |  |  | 798-FH34SRJ24S05SH99 | https://www.mouser.co.uk/ProductDetail/Hirose-Connector/FH34SRJ-24S-0.5SH99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
1 | MAX17048G+T10 | MAX17048G+T10 | SON50P200X200X80-9N | U4 | Check availability |  |  | In Stock |  | https://www.snapeda.com/parts/MAX17048G+T10/Analog+Devices/view-part/?ref=eda |  |  | 3µA 1-Cell/2-Cell Fuel Gauge with ModelGauge |  |  |  |  |  |  | Analog Devices |  |  |  |  |  | MAX17048G+T10 |  | TDFN-8 Maxim |  |  | None |  | https://www.snapeda.com/api/url_track_click_mouser/?unipart_id=329239&manufacturer=Analog Devices&part_name=MAX17048G+T10&search_term=None |  | https://www.snapeda.com/parts/MAX17048G+T10/Analog+Devices/view-part/?ref=snap
3 | MBR0530 | MBR0530 | SOD3716X135N | D3, D4, D5 | ON SEMICONDUCTOR - MBR0530 - DIODE, SCHOTTKY, 0.5A, 30V, SOD-123 |  |  | In Stock |  | https://www.snapeda.com/parts/MBR0530/Onsemi/view-part/?ref=eda |  |  | Diode Schottky 30 V 500mA Surface Mount SOD-123 |  |  |  |  |  |  | ON Semiconductor |  |  |  |  |  | MBR0530 |  | SOD-123-2 ON Semiconductor |  |  | None |  | https://www.snapeda.com/api/url_track_click_mouser/?unipart_id=179458&manufacturer=ON Semiconductor&part_name=MBR0530&search_term=None |  | https://www.snapeda.com/parts/MBR0530/Onsemi/view-part/?ref=snap
1 | MCP73831 | ESP32_WROVER_SPARKFUN-IC-POWER_MCP73831 | ESP32_WROVER_SPARKFUN-IC-POWER_SOT23-5 | MCP73831 | MCP73831T Li-Ion, Li-Pol Controller |  |  |  |  |  |  |  |  |  |  |  |  |  |  |  |  |  |  |  |  |  |  |  |  |  |  | IC-09995
6 | PGB1010603MR | PGB1010603MR | DIOC1608X36N | D6, D8, D9, D10, D11, D12 | Check availability |  |  | In Stock |  | https://www.snapeda.com/parts/PGB1010603MR/Littelfuse/view-part/?ref=eda |  |  | 150V (Typ) Clamp - Ipp Tvs Diode Surface Mount 0603 (1608 Metric) |  |  |  |  |  |  | Littelfuse Inc. |  |  |  |  |  | PGB1010603MR |  | 0603 Littelfuse Inc. |  |  | None |  | https://www.snapeda.com/api/url_track_click_mouser/?unipart_id=5659453&manufacturer=Littelfuse Inc.&part_name=PGB1010603MR&search_term=None |  | https://www.snapeda.com/parts/PGB1010603MR/Littelfuse/view-part/?ref=snap
1 | QWIIC_RIGHT_ANGLE | QWIIC_CONNECTORJS-1MM | JST04_1MM_RA | J3 | SparkFun I2C Standard Qwiic Connector |  |  |  |  |  |  |  |  |  |  |  |  |  |  |  |  |  |  |  |  |  |  |  |  |  |  | CONN-13694 |  |  |  |  |  |  |  |  | QWIIC_RIGHT_ANGLE
1 | SAMACSYS_PARTS_USB4110-GF-A | SAMACSYS_PARTS_USB4110-GF-A | SAMACSYS_PARTS_USB4110GFA | J2 | CONN USB 2.0 TYPE-C R/A SMT |  |  |  |  |  |  |  | CONN USB 2.0 TYPE-C R/A SMT |  |  | 3.26mm |  | GCT (GLOBAL CONNECTOR TECHNOLOGY) | USB4110-GF-A |  |  | 640-USB4110-GF-A | https://www.mouser.co.uk/ProductDetail/GCT/USB4110-GF-A?qs=KUoIvG%2F9IlYiZvIXQjyJeA%3D%3D
1 | SD0805S020S1R0 | ESP32_WROVER_AVX---SD0805S020S1R0_AVX_SD0805S020S1R0_0_0AVX_SD0805S020S1R0_0_0 | ESP32_WROVER_AVX---SD0805S020S1R0_AVX_SD0805S020S1R0_0 | D7 | Schottky Barrier Rectifier Diode |  |  |  | No |  |  | http://datasheets.avx.com/schottky.pdf |  | DIODE SCHOTTKY 20V 1A 0805 | 478-7800-1-ND |  | yes |  |  | AVX |  | 581-SD0805S020S1R0 |  |  |  |  |  | 0805 (2012 metric) |  | D |  |  |  | yes |  |  |  | +125°C | -55°C
1 | SI1308EDL-T1-GE3 | SI1308EDL-T1-GE3 | SOT65P210X110-3N | Q3 | MOSFET N-Ch 30V 1.5A TrenchFET SC70 Vishay Si1308EDL-T1-GE3 N-channel MOSFET Transistor, 1.5 A, 30 V, 3-Pin SC-70 |  |  | In Stock |  | https://www.snapeda.com/parts/SI1308EDL-T1-GE3/Vishay+Siliconix/view-part/?ref=eda |  |  | Si1308EDL-T1-GE3 N-channel MOSFET Transistor | 1.5 A | 30 V | 3-Pin SC-70 | Siliconix / Vishay SI1308EDL-T1-GE3 |  |  |  |  |  |  | Vishay Siliconix |  |  |  |  |  | SI1308EDL-T1-GE3 |  | SOT-323 Vishay Semiconductor |  |  | None |  | https://www.snapeda.com/api/url_track_click_mouser/?unipart_id=274603&manufacturer=Vishay Siliconix&part_name=SI1308EDL-T1-GE3&search_term=None |  | https://www.snapeda.com/parts/SI1308EDL-T1-GE3/Vishay+Siliconix/view-part/?ref=snap
17 | TPTP20R | TPTP20R | TP20R | TP1, TP2, TP3, TP4, TP5, TP6, TP7, TP8, TP9, TP10, TP11, TP12, TP13, TP14, TP15, TP16, TP17 | Test pad |  |  |  |  |  |  |  |  |  |  |  |  |  |  |  |  |  |  |  |  |  |  |  | 2
1 | USBLC6-2SC6Y | USBLC6-2SC6Y | SOT95P280X145-6N | D1 | Low Cap. ESD Protection Auto SOT-23-6 STMicroelectronics USBLC6-2SC6Y, Dual Uni-Directional TVS Diode Array, 6-Pin SOT-23 |  |  | In Stock |  | https://www.snapeda.com/parts/USBLC6-2SC6Y/STMicroelectronics/view-part/?ref=eda |  |  | 17V Clamp 5A (8/20µs) Ipp Tvs Diode Surface Mount SOT-23-6 |  |  |  |  |  |  | STMicroelectronics |  |  |  |  |  | USBLC6-2SC6Y |  | SOT-23-6 STMicroelectronics |  |  | None |  |  |  | https://www.snapeda.com/parts/USBLC6-2SC6Y/STMicroelectronics/view-part/?ref=snap
1 | W25Q512JVEIQ | W25Q512JVEIQ | SON127P600X800X80-9N | U1 | Check availability |  |  | In Stock |  | https://www.snapeda.com/parts/W25Q512JVEIQ/Winbond+Electronics/view-part/?ref=eda |  |  | FLASH - NOR Memory IC 512Mb (64M x 8) SPI - Quad I/O 133 MHz 8-WSON (8x6) |  |  |  |  |  |  | Winbond Electronics |  |  |  |  |  | W25Q512JVEIQ |  | Package |  |  | None |  |  |  | https://www.snapeda.com/parts/W25Q512JVEIQ/Winbond+Electronics/view-part/?ref=snap
1 | XC6220A331MR-G | XC6220A331MR-G | SOT95P280X120-5N | IC4 | LDO Voltage Regulators |  |  |  |  |  |  |  | LDO Voltage Regulators |  |  | 1.2mm |  | Torex | XC6220A331MR-G |  |  | 865-XC6220A331MR-G | https://www.mouser.co.uk/ProductDetail/Torex-Semiconductor/XC6220A331MR-G?qs=AsjdqWjXhJ8ZSWznL1J0gg%3D%3D

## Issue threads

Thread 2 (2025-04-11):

Missing GND pour due to lack of vias

IonHaruta, 2025-04-11:
În zona evidențiată, GND pour nu se aplică din cauza lipsei de via-uri conectate la GND — recomand adăugarea unor via-uri în spațiile libere pentru a rezolva problema.

Closed 2025-04-14.

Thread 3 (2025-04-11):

USB4110GFA too far from PCB edge

IonHaruta, 2025-04-11:
Componenta SAMACSYS_PARTS_USB4110GFA este poziționată prea departe de marginea plăcii, ceea ce poate crea probleme de aliniere sau acces în cadrul carcasei. Sugerez repoziționarea acesteia mai aproape de margine, conform cerințelor mecanice ale designului.

Closed 2025-04-14.

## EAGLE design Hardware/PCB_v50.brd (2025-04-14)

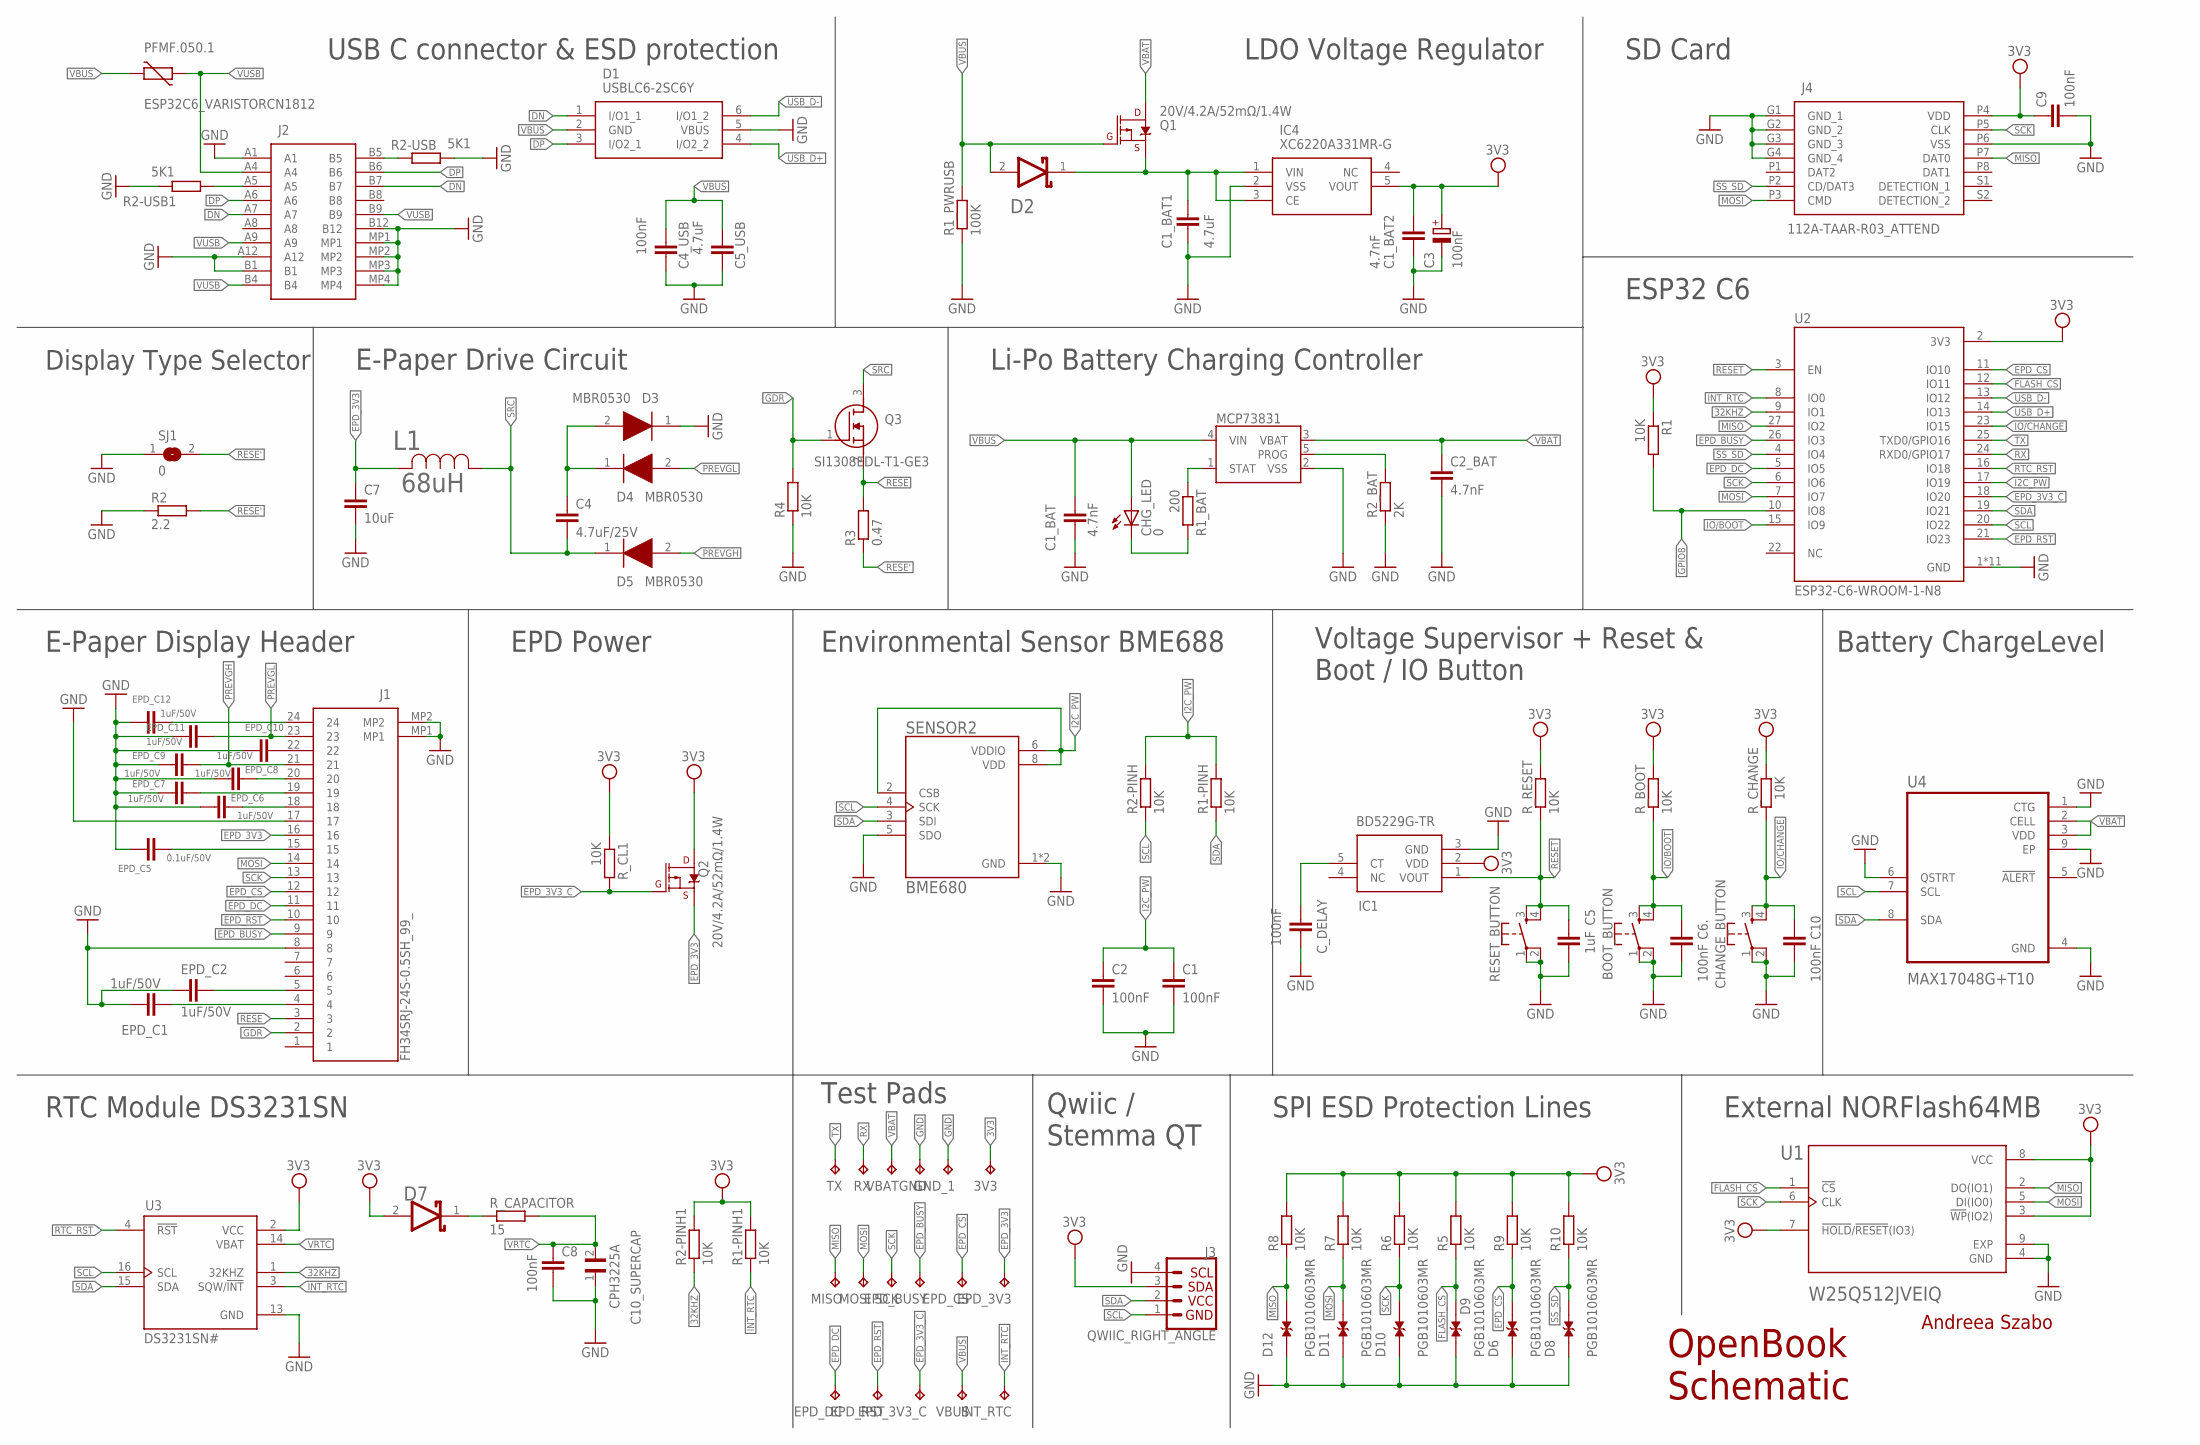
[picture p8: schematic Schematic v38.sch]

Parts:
3V3: TPTP20R; TP20R
BOOT_BUTTON: BUTTON_CUSYOMV1; MYBUTTON
C1, C2, C4_USB, C6., C8, C9, C10: 100nF; ESP32_WROVER_EAGLE-LTSPICE_C0402
C1_BAT, C1_BAT2, C2_BAT: 4.7nF; ESP32_WROVER_EAGLE-LTSPICE_C0402
C1_BAT1, C5_USB: 4.7uF; ESP32_WROVER_EAGLE-LTSPICE_C0402
C3: 100nF; RCL_CT3528
C4: 4.7uF/25V; ESP32_WROVER_EAGLE-LTSPICE_C0402
C5: 1uF; ESP32_WROVER_EAGLE-LTSPICE_C0402
C7: 10uF; ESP32_WROVER_EAGLE-LTSPICE_C0402
C10_SUPERCAP: CPH3225A; CAPCP3225X100N
CHANGE_BUTTON: BUTTON_CUSYOMV1; MYBUTTON
CHG_LED: 0; ADAFRUIT_CHIP-LED0603
C_DELAY: 100nF; ESP32_WROVER_EAGLE-LTSPICE_C0402
D1: USBLC6-2SC6Y; SOT95P280X145-6N
D2: ESP32_WROVER_AVX---SD0805S020S1R0_AVX_SD0805S020S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; ESP32_WROVER_AVX---SD0805S020S1R0_AVX_SD0805S020S1R0_0
D3, D4, D5: MBR0530; SOD3716X135N
D6, D8, D9, D10, D11, D12: PGB1010603MR; DIOC1608X36N
D7: SD0805S020S1R0; ESP32_WROVER_AVX---SD0805S020S1R0_AVX_SD0805S020S1R0_0
EPD_3V3, EPD_3V3_C: TPTP20R; TP20R
EPD_BUSY: TPTP20R; TP20R
EPD_C1, EPD_C2, EPD_C6, EPD_C7, EPD_C8, EPD_C9, EPD_C10, EPD_C11, EPD_C12: 1uF/50V; ESP32_WROVER_EAGLE-LTSPICE_C0402
EPD_C5: 0.1uF/50V; ESP32_WROVER_EAGLE-LTSPICE_C0402
EPD_CS: TPTP20R; TP20R
EPD_DC: TPTP20R; TP20R
EPD_RST: TPTP20R; TP20R
GND: TPTP20R; TP20R
GND_1: TPTP20R; TP20R
IC1: BD5229G-TR; SOT95P280X125-5N
IC4: XC6220A331MR-G; SOT95P280X120-5N
INT_RTC: TPTP20R; TP20R
J1: FH34SRJ-24S-0.5SH_99_; FH34SRJ24S05SH99
J2: SAMACSYS_PARTS_USB4110-GF-A; SAMACSYS_PARTS_USB4110GFA
J3: QWIIC_RIGHT_ANGLE; JST04_1MM_RA
J4: 112A-TAAR-R03_ATTEND; 112ATAARR03ATTEND
L1: 68uH; IND_4828-WE-TPC_WRE
MCP73831: MCP73831; ESP32_WROVER_SPARKFUN-IC-POWER_SOT23-5
MISO: TPTP20R; TP20R
MOSI: TPTP20R; TP20R
PFMF.050.1: ESP32C6_VARISTORCN1812; ESP32C6_VARISTOR_CT/CN1812
Q1, Q2: 20V/4.2A/52mΩ/1.4W; ESP32_WROVER_SPARKFUN-DISCRETESEMI_SOT23-3
Q3: SI1308EDL-T1-GE3; SOT65P210X110-3N
R1, R1-PINH, R1-PINH1, R2-PINH, R2-PINH1, R4, R5, R6, R7, R8, R9, R10: 10K; ESP32_WROVER_EAGLE-LTSPICE_R0402
R1_BAT: 200; ESP32_WROVER_EAGLE-LTSPICE_R0402
R1_PWRUSB: 100K; ESP32_WROVER_EAGLE-LTSPICE_R0402
R2: 2.2; ESP32_WROVER_EAGLE-LTSPICE_R0402
R2-USB, R2-USB1: 5K1; ESP32_WROVER_EAGLE-LTSPICE_R0402
R2_BAT: 2K; ESP32_WROVER_EAGLE-LTSPICE_R0402
R3: 0.47; ESP32_WROVER_EAGLE-LTSPICE_R0402
RESET_BUTTON: BUTTON_CUSYOMV1; MYBUTTON
RX: TPTP20R; TP20R
R_BOOT: 10K; ESP32_WROVER_EAGLE-LTSPICE_R0402
R_CAPACITOR: 15; ESP32_WROVER_EAGLE-LTSPICE_R0402
R_CHANGE: 10K; ESP32_WROVER_EAGLE-LTSPICE_R0402
R_CL1: 10K; ESP32_WROVER_EAGLE-LTSPICE_R0402
R_RESET: 10K; ESP32_WROVER_EAGLE-LTSPICE_R0402
SCK: TPTP20R; TP20R
SENSOR2: BME680; ESP32_WROVER_BME680_PSON80P300X300X100-8N
SJ1: 0; SJ
TX: TPTP20R; TP20R
U1: W25Q512JVEIQ; SON127P600X800X80-9N
U2: ESP32-C6-WROOM-1-N8; XCVR_ESP32-C6-WROOM-1-N8
U3: DS3231SN#; SOIC127P1032X265-16N
U4: MAX17048G+T10; SON50P200X200X80-9N
VBAT: TPTP20R; TP20R
VBUS: TPTP20R; TP20R

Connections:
3V3: 3V3.TP, C1_BAT2.1, C3.+, C9.1, D7.2 (ANODE), IC1.2 (VDD), IC4.5 (VOUT), J3.3, J4.P4 (VDD), Q2.3 (D), R1.1, R1-PINH1.2, R2-PINH1.2, R5.2, R6.2, R7.2, R8.2, R9.2, R10.2, R_BOOT.2, R_CHANGE.2, R_CL1.1, R_RESET.2, U1.3 (!WP!(IO2)), U1.7 (!HOLD!/!RESET!(IO3)), U1.8 (VCC), U2.2 (3V3), U3.2 (VCC)
32KHZ: R2-PINH1.1, U2.9 (IO1), U3.1 (32KHZ)
DN: D1.1 (I/O1_1), J2.A7, J2.B7
DP: D1.3 (I/O2_1), J2.A6, J2.B6
EPD_3V3: C7.1, EPD_3V3.TP, J1.16, L1.2, Q2.2 (S)
EPD_3V3_C: EPD_3V3_C.TP, Q2.1 (G), R_CL1.2, U2.18 (IO20)
EPD_BUSY: EPD_BUSY.TP, J1.9, U2.26 (IO3)
EPD_CS: D6.2, EPD_CS.TP, J1.12, R9.1, U2.11 (IO10)
EPD_DC: EPD_DC.TP, J1.11, U2.5 (IO5)
EPD_RST: EPD_RST.TP, J1.10, U2.21 (IO23)
FLASH_CS: D9.2, R5.1, U1.1 (!CS), U2.12 (IO11)
GDR: J1.2, Q3.1 (G), R4.2
GND: BOOT_BUTTON.1, BOOT_BUTTON.2, C1.2, C1_BAT.2, C1_BAT1.2, C1_BAT2.2, C2.2, C2_BAT.2, C3.-, C4_USB.2, C5.2, C5_USB.2, C6..2, C7.2, C8.2, C9.2, C10.2, C10_SUPERCAP.1, CHANGE_BUTTON.1, CHANGE_BUTTON.2, C_DELAY.2, D1.5 (VBUS), D3.1 (K), D6.1, D8.1, D9.1, D10.1, D11.1, D12.1, EPD_C1.2, EPD_C2.2, EPD_C5.2, EPD_C6.2, EPD_C7.2, EPD_C8.2, EPD_C9.2, EPD_C10.2, EPD_C11.2, EPD_C12.2, GND.TP, GND_1.TP, IC1.3 (GND), IC4.2 (VSS), J1.8, J1.17, J1.MP1, J1.MP2, J2.A1, J2.A12, J2.B1, J2.B12, J2.MP1, J2.MP2, J2.MP3, J2.MP4, J3.4, J4.G1 (GND_1), J4.G2 (GND_2), J4.G3 (GND_3), J4.G4 (GND_4), J4.P6 (VSS), MCP73831.2 (VSS), R1_PWRUSB.1, R2.1, R2-USB.2, R2-USB1.1, R2_BAT.1, R4.1, RESET_BUTTON.1, RESET_BUTTON.2, SENSOR2.1 (GND), SENSOR2.5 (SDO), SENSOR2.7 (GND), SJ1.1, U1.4 (GND), U1.9 (EXP), U2.1 (GND), U2.28 (GND), U2.29_1 (GND), U2.29_2 (GND), U2.29_3 (GND), U2.29_4 (GND), U2.29_5 (GND), U2.29_6 (GND), U2.29_7 (GND), U2.29_8 (GND), U2.29_9 (GND), U3.13 (GND), U4.1 (CTG), U4.4 (GND), U4.6 (QSTRT), U4.9 (EP)
GPIO8: R1.2, U2.10 (IO8)
I2C_PW: C1.1, C2.1, R1-PINH.2, R2-PINH.2, SENSOR2.2 (CSB), SENSOR2.6 (VDDIO), SENSOR2.8 (VDD), U2.17 (IO19)
INT_RTC: INT_RTC.TP, R1-PINH1.1, U2.8 (IO0), U3.3 (SQW/!INT)
IO/BOOT: BOOT_BUTTON.3, BOOT_BUTTON.4, C6..1, R_BOOT.1, U2.15 (IO9)
IO/CHANGE: C10.1, CHANGE_BUTTON.3, CHANGE_BUTTON.4, R_CHANGE.1, U2.23 (IO15)
MISO: D12.2, J4.P7 (DAT0), MISO.TP, R8.1, U1.2 (DO(IO1)), U2.27 (IO2)
MOSI: D11.2, J1.14, J4.P3 (CMD), MOSI.TP, R7.1, U1.5 (DI(IO0)), U2.7 (IO7)
unnamed: J2.A5, R2-USB1.2
unnamed: J2.B5, R2-USB.1
unnamed: CHG_LED.C, R1_BAT.2
unnamed: C1_BAT1.1, D2.1 (CATHODE), IC4.1 (VIN), IC4.3 (CE), Q1.2 (S)
unnamed: MCP73831.5 (PROG), R2_BAT.2
unnamed: MCP73831.1 (STAT), R1_BAT.1
unnamed: EPD_C5.1, J1.15
unnamed: EPD_C1.1, J1.4
unnamed: EPD_C6.1, J1.18
unnamed: C4.1, D3.2 (A), D4.1 (K)
unnamed: EPD_C12.1, J1.24
unnamed: C_DELAY.1, IC1.5 (CT)
unnamed: EPD_C10.1, J1.22
unnamed: EPD_C8.1, J1.20
unnamed: EPD_C7.1, J1.19
unnamed: EPD_C2.1, J1.5
unnamed: D7.1 (CATHODE), R_CAPACITOR.1
PREVGH: D5.2 (A), EPD_C9.1, J1.21
PREVGL: D4.2 (A), EPD_C11.1, J1.23
RESE: J1.3, Q3.2 (S), R3.2
RESE': R2.2, R3.1, SJ1.2
RESET: C5.1, IC1.1 (VOUT), RESET_BUTTON.3, RESET_BUTTON.4, R_RESET.1, U2.3 (EN)
RTC_RST: U2.16 (IO18), U3.4 (!RST)
RX: RX.TP, U2.24 (RXD0/GPIO17)
SCK: D10.2, J1.13, J4.P5 (CLK), R6.1, SCK.TP, U1.6 (CLK), U2.6 (IO6)
SCL: J3.1, R2-PINH.1, SENSOR2.4 (SCK), U2.20 (IO22), U3.16 (SCL), U4.7 (SCL)
SDA: J3.2, R1-PINH.1, SENSOR2.3 (SDI), U2.19 (IO21), U3.15 (SDA), U4.8 (SDA)
SRC: C4.2, D5.1 (K), L1.1, Q3.3 (D)
SS_SD: D8.2, J4.P2 (CD/DAT3), R10.1, U2.4 (IO4)
TX: TX.TP, U2.25 (TXD0/GPIO16)
USB_D+: D1.4 (I/O2_2), U2.14 (IO13)
USB_D-: D1.6 (I/O1_2), U2.13 (IO12)
VBAT: C2_BAT.1, MCP73831.3 (VBAT), Q1.3 (D), U4.2 (CELL), U4.3 (VDD), VBAT.TP
VBUS: C1_BAT.1, C4_USB.1, C5_USB.1, CHG_LED.A, D1.2 (GND), D2.2 (ANODE), MCP73831.4 (VIN), PFMF.050.1.2, Q1.1 (G), R1_PWRUSB.2, VBUS.TP
VRTC: C8.1, C10_SUPERCAP.2, R_CAPACITOR.2, U3.14 (VBAT)
VUSB: J2.A4, J2.A9, J2.B4, J2.B9, PFMF.050.1.1

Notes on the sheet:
USB C connector & ESD protection
LDO Voltage Regulator
SD Card
Display Type Selector
E-Paper Drive Circuit
Li-Po Battery Charging Controller
ESP32 C6
E-Paper Display Header
EPD Power
Environmental Sensor BME688
Voltage Supervisor + Reset & Boot / IO Button
Battery ChargeLevel
RTC Module DS3231SN
Test Pads
Qwiic / Stemma QT
SPI ESD Protection Lines
External NORFlash64MB
OpenBook Schematic
Andreea Szabo

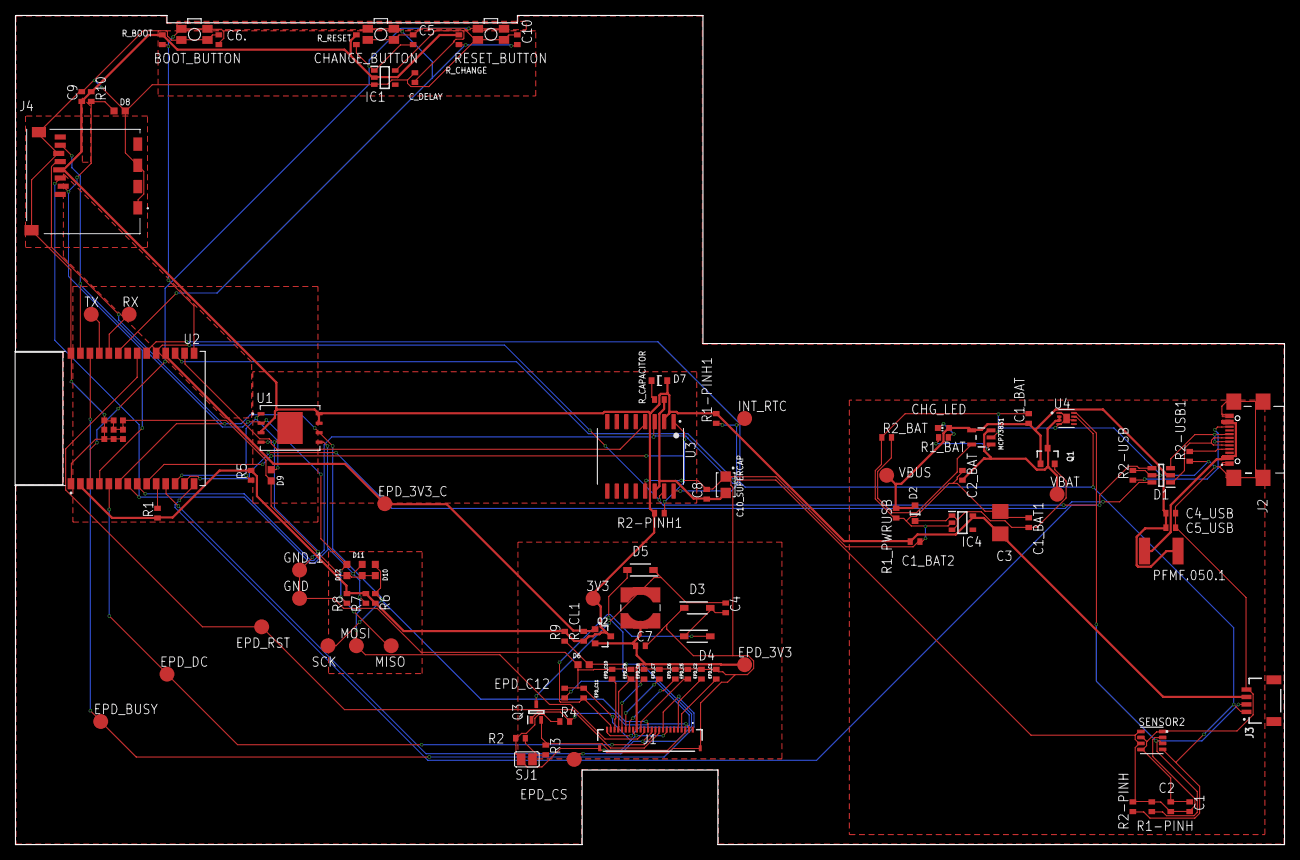
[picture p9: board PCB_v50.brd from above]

Board: 2 copper layers, 170.2 x 111.2 mm, 103 parts (0 on the bottom side), 56 nets.

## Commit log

2025-04-06 added project
    [PCB v42.csv, PCB.brd, PnP_PCB v42_front.csv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]
2025-04-14 update hardware
    [PCB.brd, PCB_v50.brd, Schematic v38.sch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]

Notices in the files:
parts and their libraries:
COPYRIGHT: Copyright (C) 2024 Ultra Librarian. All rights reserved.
